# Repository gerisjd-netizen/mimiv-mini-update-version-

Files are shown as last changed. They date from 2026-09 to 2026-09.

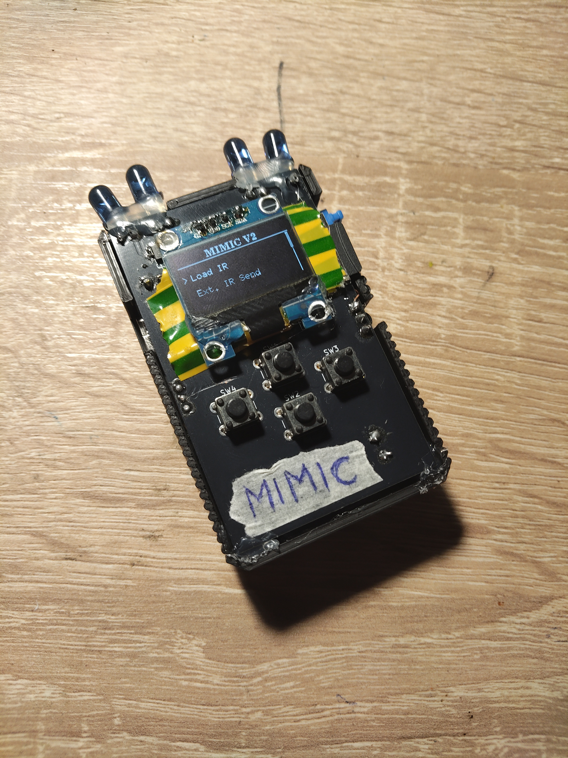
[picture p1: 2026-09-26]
mimic_mini/IMG_20260921_205225.jpg

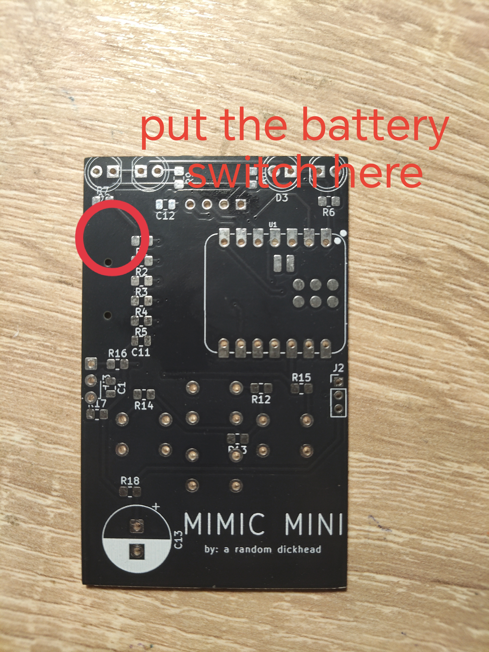
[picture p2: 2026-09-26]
mimic_mini/IMG_20260921_205933.jpg

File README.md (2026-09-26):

# MIMIC Mini - IR Cloner

MIMIC Mini is a compact infrared (IR) cloner and universal remote device. It is capable of reliably transmitting IR signals at ranges of up to 10–15 meters. It is fully compatible with Flipper Zero `.ir` files and provides up to 3 days of battery life under normal usage. Equipped with microSD card storage and an integrated receiver unit, it can record and save captured signals in both raw `.txt` and standard `.ir` formats.

---

## 🛠 Features

* **Extended Range:** Transmits IR signals up to 10–15 meters.
* **Flipper Zero Compatibility:** Natively supports `.ir` signal files.
* **Long Battery Life:** Up to 3 days of standard operational time.
* **Expandable Storage:** MicroSD card support for storing large databases of IR codes.
* **Signal Capture:** Built-in receiver capable of capturing and saving raw TXT or structured IR formats.

---

## 🏗 Housing & Assembly Instructions

1. **Belt Clip Attachment:**
   * The bill of materials (BOM) does not include the 3mm press-fit brass inserts or corresponding screws. 
   * The belt clip mount should be glued directly to the back of the enclosure for easy belt attachment.

2. **Display Insulation (CRITICAL):**
   * Before inserting the display, **apply insulating adhesive tape (e.g., Kapton or electrical tape) to the back of the display board**.
   * *Warning:* Failure to insulate the back of the display may cause a short circuit against the MicroSD card socket.

3. **IR LED Alignment:**
   * Pay close attention to the positioning and angles of the IR LEDs. 
   * If all LEDs are pointing straight forward, the transmission beam spread will be reduced, making it harder to aim at target devices. Angle them slightly outward to maximize signal coverage.

4. **Battery & Power Switch Wiring:**
   * Solder the battery directly to the `BAT` pads on the bottom of the ESP32-C3 board.
   * Wire the power switch in series with the positive battery lead to break the circuit.
   * Glue the power switch to the side of the PCB as demonstrated in the assembly photos.

---

## 📁 SD Card Structure & Usage

Upon inserting an SD card for the first time, the device will automatically generate three directories:
### 1. `saved_ir/`
* Captured IR signals are saved here. You can set the target capture format (`.ir` or `.txt`) in the device settings menu.
* Files in this folder can be renamed freely.
* If you place a multi-code `.ir` file in this folder, opening it on the device will display a sub-menu containing each individual code, allowing you to trigger them selectively one by one.

### 2. `universal/`
* If a multi-code `.ir` file is placed in the `universal` directory, the device will sequentially play back **all** IR codes inside the file one after another (e.g., universal power-off sequence). You will not be able to select individual codes in this mode.

---

## ⚙️ Settings

* **Transmitter Selection:** Through the system settings, you can toggle between using the internal IR transmitter array or an external IR module/emitter.

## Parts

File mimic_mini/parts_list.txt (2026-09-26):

100.337.50	4	TACT-65K-F
100.285.00	1	470uF/16V LOW ESR & IMP.
100.264.87	4	TSAL-6200
100.427.11	1	4.7uF / 25V
100.011.22	2	100 nF / 50V
100.496.54	8	SMD0805-10K-0.1%
100.012.50	4	SMD0805-22R-5%
100.449.24	1	100R 1%
100.011.43	2	SMD0805-100K-5%
100.011.72	1	SMD0805-33K-5%
100.011.56	1	SMD0805-1R-5%
100.461.70	1	TSOP38238
100.510.43	1	XIAO-ESP32-C3
100.483.04	1	D096-12864-I2C-GV-WH
100.329.15	1	ZL262-3SG
100.399.59	1	AO3400A
100.410.19	1	MCSP-Q-08-A-SG-T/R
100.399.65	1	BS-800-L
100.490.28	1	AKY0384-LP601730

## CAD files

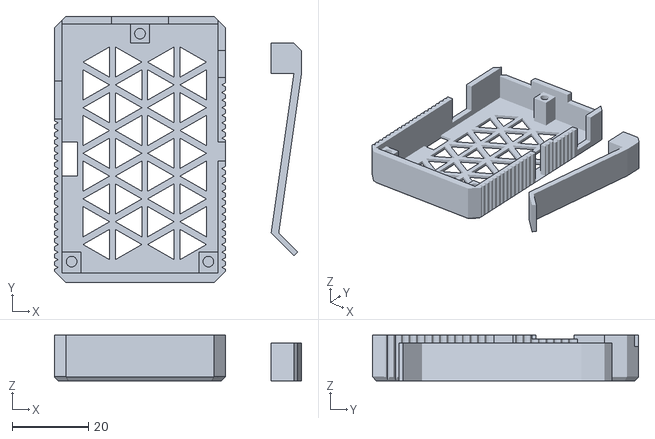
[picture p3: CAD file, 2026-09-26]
mimic_mini/mimic_mini_housing.stl
65.0 x 70.0 x 12.0

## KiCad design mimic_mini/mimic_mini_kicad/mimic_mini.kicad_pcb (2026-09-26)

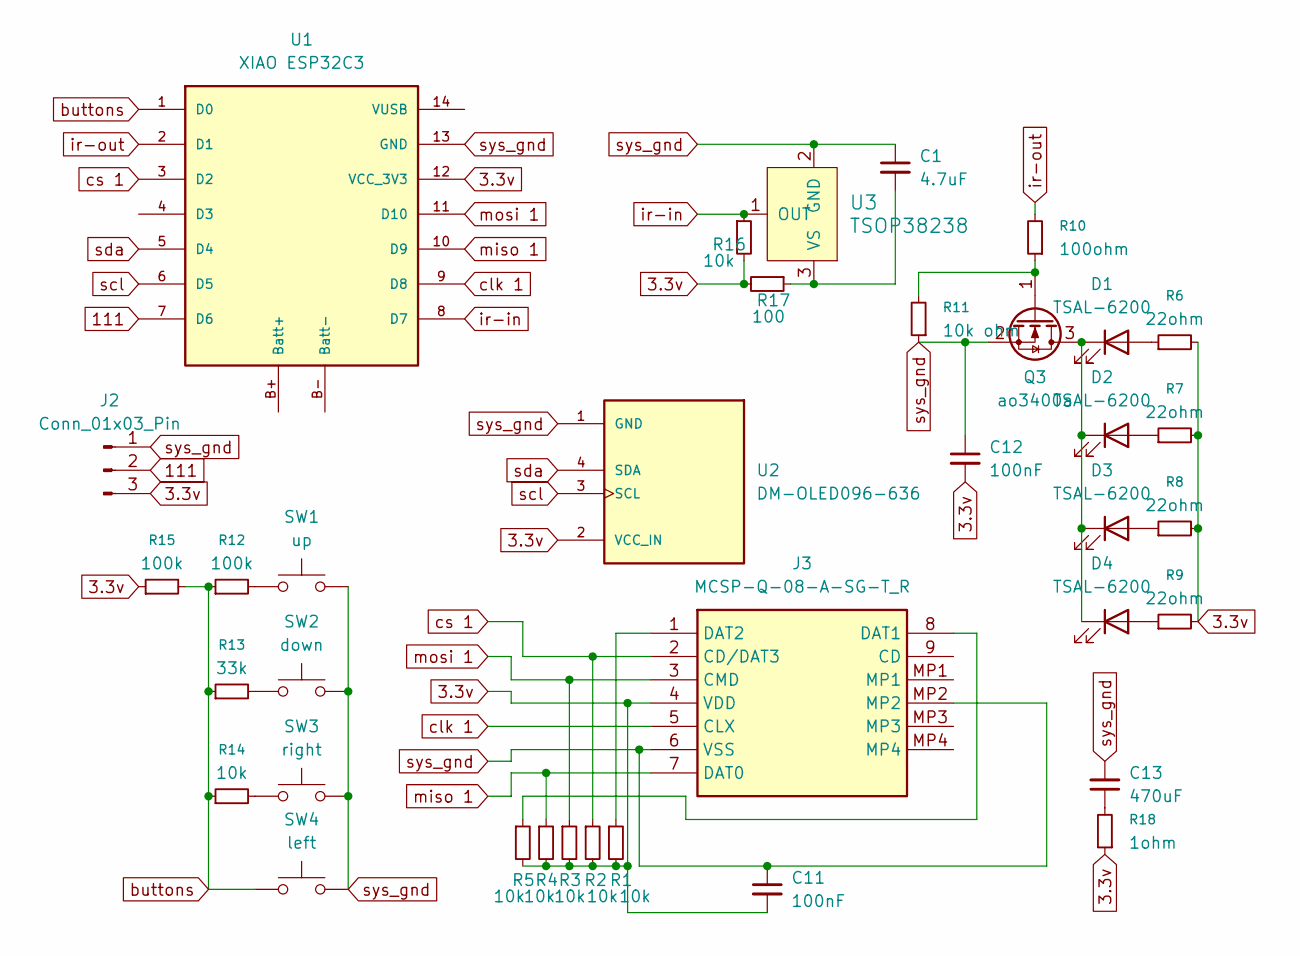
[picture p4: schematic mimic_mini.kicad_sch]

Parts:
C1: 4.7uF; C_0805_2012Metric
C11, C12: 100nF; C_0805_2012Metric
C13: 470uF; CP_Radial_D10.0mm_P3.80mm
D1, D2, D3, D4: TSAL-6200; LED_D5.0mm
J2: Conn_01x03_Pin; PinHeader_1x03_P2.54mm_Vertical
J3: MCSP-Q-08-A-SG-T_R; MCSPQ08ASGTR; Manufacturer_Part_Number MCSP-Q-08-A-SG-T/R
Q3: ao3400a; SOT-23
R1, R2, R3, R4, R5, R14, R16: 10k; R_0805_2012Metric_Pad1.20x1.40mm_HandSolder
R6, R7, R8, R9: 22ohm; R_0805_2012Metric_Pad1.20x1.40mm_HandSolder
R10: 100ohm; R_0805_2012Metric_Pad1.20x1.40mm_HandSolder
R11: 10k ohm; R_0805_2012Metric_Pad1.20x1.40mm_HandSolder
R12, R15: 100k; R_0805_2012Metric_Pad1.20x1.40mm_HandSolder
R13: 33k; R_0805_2012Metric_Pad1.20x1.40mm_HandSolder
R17: 100; R_0805_2012Metric_Pad1.20x1.40mm_HandSolder
R18: 1ohm; R_0805_2012Metric_Pad1.20x1.40mm_HandSolder
SW1: up; SW_PUSH_6mm
SW2: down; SW_PUSH_6mm
SW3: right; SW_PUSH_6mm
SW4: left; SW_PUSH_6mm
U1: XIAO ESP32C3; XIAO-ESP32-C3-DIP-SMD
U2: DM-OLED096-636; MODULE_DM-OLED096-636; PARTREV 2018-09-10
U3: TSOP38238; Vishay_MINICAST-3Pin; MPN TSOP38238; Digi-Key_PN 751-1227-ND

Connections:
3.3v: C11.2, C12.2, J2.3, J3.4 (VDD), R1.2, R2.2, R3.2, R4.2, R5.2, R6.2, R7.2, R8.2, R9.2, R15.1, R16.2, R17.2, R18.1, U1.12 (VCC_3V3), U2.2 (VCC_IN)
111: J2.2, U1.7 (D6)
unnamed: C13.1, R18.2
unnamed: D1.2 (A), R6.1
unnamed: D1.1 (K), D2.1 (K), D3.1 (K), D4.1 (K), Q3.3 (D)
unnamed: D2.2 (A), R7.1
unnamed: D3.2 (A), R8.1
unnamed: D4.2 (A), R9.1
unnamed: J3.8 (DAT1), R5.1
unnamed: J3.1 (DAT2), R1.1
unnamed: Q3.1 (G), R10.1, R11.2
unnamed: R12.2, SW1.1
unnamed: R13.2, SW2.1
unnamed: R14.2, SW3.1
unnamed: C1.2, R17.1, U3.3 (VS)
buttons: R12.1, R13.1, R14.1, R15.2, SW4.1, U1.1 (D0)
clk 1: J3.5 (CLX), U1.9 (D8)
cs 1: J3.2 (CD/DAT3), R2.1, U1.3 (D2)
ir-in: R16.1, U1.8 (D7), U3.1 (OUT)
ir-out: R10.2, U1.2 (D1)
miso 1: J3.7 (DAT0), R4.1, U1.10 (D9)
mosi 1: J3.3 (CMD), R3.1, U1.11 (D10)
scl: U1.6 (D5), U2.3 (SCL)
sda: U1.5 (D4), U2.4 (SDA)
sys_gnd: C1.1, C11.1, C12.1, C13.2, J2.1, J3.6 (VSS), J3.MP2, Q3.2 (S), R11.1, SW1.2, SW2.2, SW3.2, SW4.2, U1.13 (GND), U2.1 (GND), U3.2 (GND)

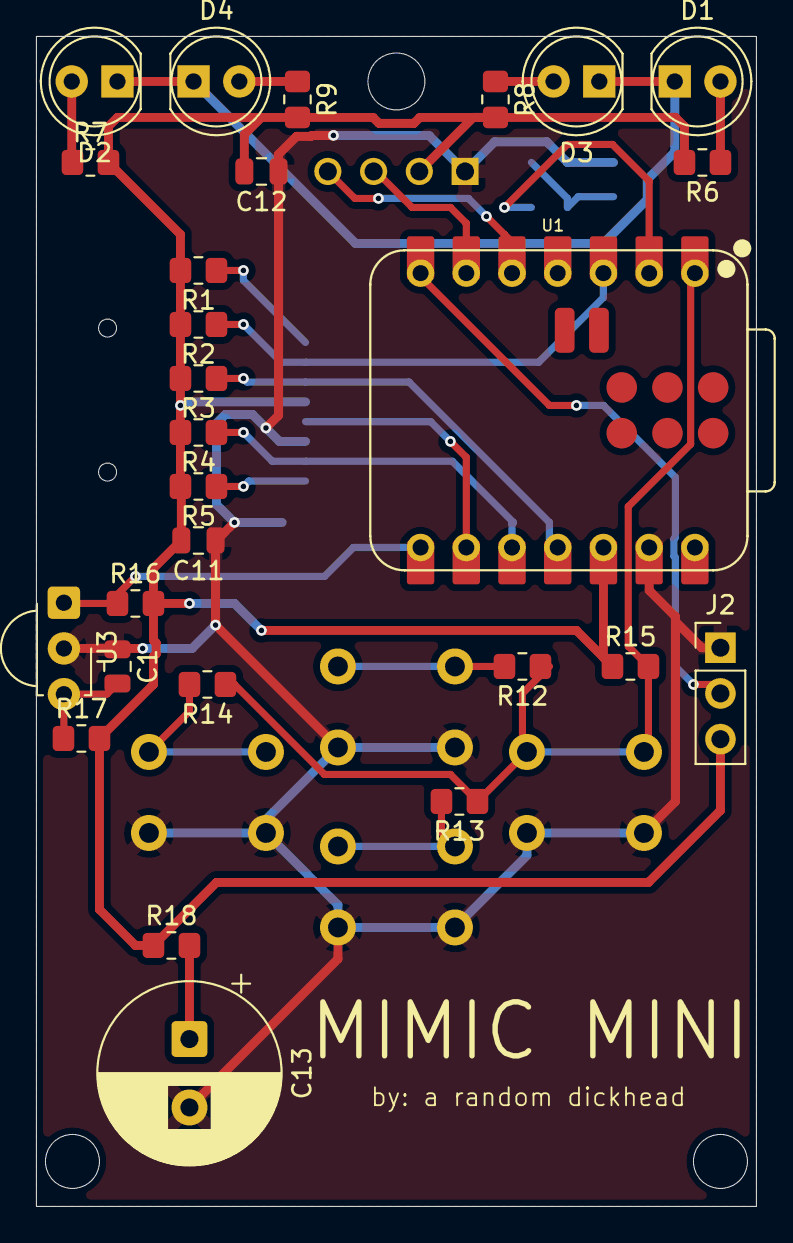
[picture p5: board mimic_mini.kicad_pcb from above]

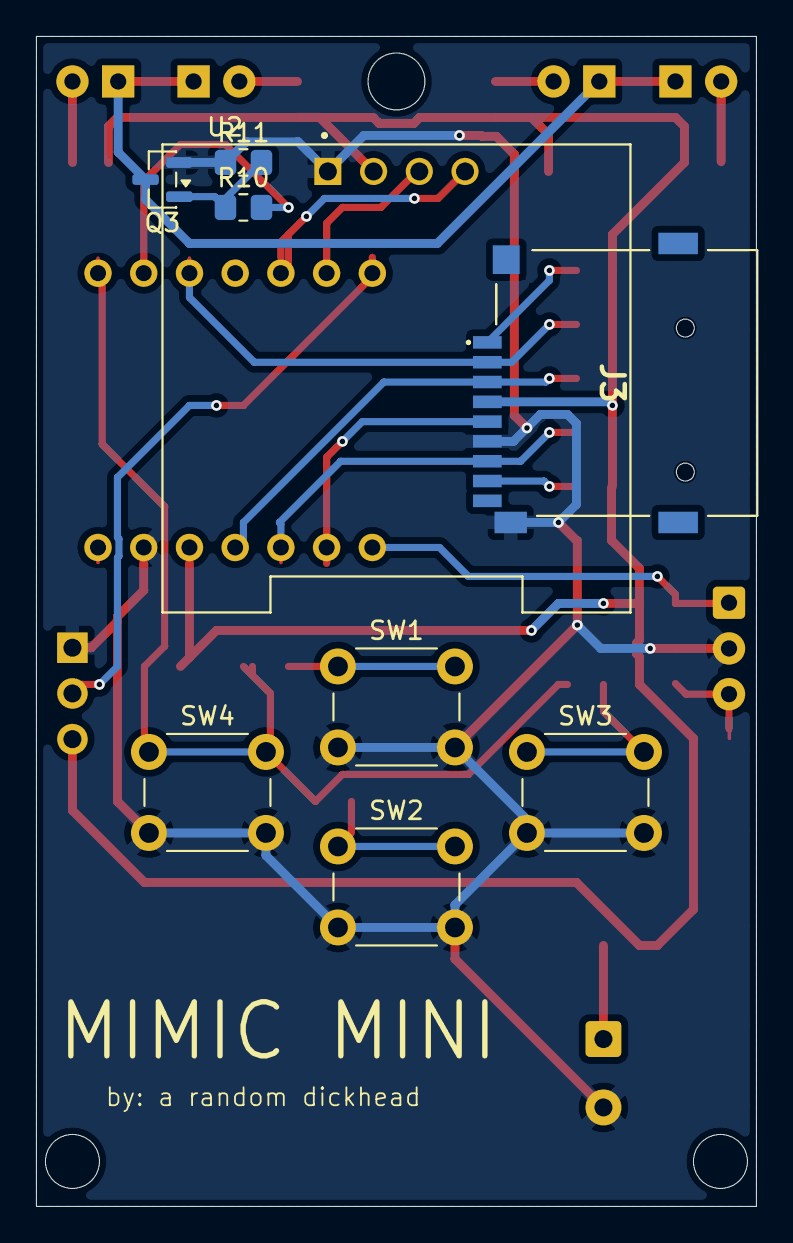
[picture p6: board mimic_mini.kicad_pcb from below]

Board: 2 copper layers, 40.0 x 65.0 mm, 36 parts (9 on the bottom side), 25 nets.

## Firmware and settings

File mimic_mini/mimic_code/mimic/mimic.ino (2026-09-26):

#include <Arduino.h>
#include <SPI.h>
#include <SD.h>
#include <U8g2lib.h>
#include <Wire.h>
#include <EEPROM.h>
#include "esp_sleep.h"

// --- EEPROM CÍMEK ---
#define EEPROM_SIZE 2
#define EEPROM_SAVE_FORMAT_ADDR 0
#define EEPROM_LED_PIN_ADDR 1

// --- IRREMOTE CONFIGURATION ---
#define IR_SEND_INTERNAL_PIN 3   // Belső IR adó LED: GPIO 3
#define IR_SEND_EXTERNAL_PIN 21  // Külső IR adó adatvonala: GPIO 21 (D6)
#define IR_RECEIVE_PIN 20        // IR vevő modul: GPIO 20
#define RAW_BUFFER_LENGTH 400    // Puffer méret a nyers pulzusokhoz

// --- SEBESSÉG BEÁLLÍTÁS ---
const uint16_t IR_GAP_MS = 50; 

#include <IRremote.hpp>

// --- PINOUT DEFINITIONS ---
#define SD_CS   4   // D2 láb = GPIO 4
#define SD_CLK  8   // D8 láb = GPIO 8
#define SD_MISO 9   // D9 láb = GPIO 9
#define SD_MOSI 10  // D10 láb = GPIO 10
#define ANALOG_PIN 2 // Gomb-létra: GPIO 2 (ADC1_CH2)

// Deep sleep inaktivitási időkorlát (30 másodperc)
#define SLEEP_TIMEOUT_MS 30000 
uint32_t lastActivityTime = 0;

// SD Kártya állapotának figyelése
bool sdInitialized = false;

// OLED Kijelző (XIAO ESP32-C3: SDA=6, SCL=7)
U8G2_SSD1306_128X64_NONAME_F_HW_I2C u8g2(U8G2_R0, U8X8_PIN_NONE);

// --- AUTO-REPEAT GOMB MÁTRIX VÁLTOZÓK ---
enum ButtonType { BTN_NONE, BTN_LEFT, BTN_RIGHT, BTN_DOWN, BTN_UP };

ButtonType lastPhysicalButton = BTN_NONE;
unsigned long buttonPressStart = 0;
unsigned long lastRepeatTime = 0;
bool isHolding = false;

const unsigned long HOLD_DELAY_MS = 350;     // Ennyi nyomva tartás után indul a gyorstüzelés
const unsigned long REPEAT_INTERVAL_MS = 100; // Ismétlési sebesség (ms)

// Gomb trigger jelzők a loop-nak
bool rightTriggered = false;
bool downTriggered  = false;
bool leftTriggered   = false;
bool upTriggered     = false;

// Nyers gombállapotok az olyan folyamatos mozgásokhoz, mint a Pong
bool rightRaw = false;
bool downRaw  = false;
bool leftRaw   = false;
bool upRaw     = false;

// SD Fájllista (IR, Univ és Jegyzetekhez)
#define MAX_FILES 50
String fileList[MAX_FILES];
int totalFiles = 0;
int selectedIndex = 0;

// Több jelet tartalmazó fájlok almenüje
#define MAX_SUB_SIGNALS 40
String subSignalNames[MAX_SUB_SIGNALS];
int totalSubSignals = 0;
int selectedSubIndex = 0;
String currentMultiFilePath = "";

// Jegyzet megjelenítéshez sorok
#define MAX_NOTE_LINES 100
String noteLines[MAX_NOTE_LINES];
int totalNoteLines = 0;
int noteScrollIndex = 0;

// Beállítások opciók
bool saveAsFlipper = true; // true = Flipper .ir, false = Raw .txt
bool useExternalIR = false; // true = External, false = Internal

// Rendszerállapotok
enum SystemState {
  MAIN_MENU,
  IR_MENU,
  LOAD_IR_LIST,
  LOAD_UNIV_LIST,
  SUB_IR_LIST,
  SAVE_IR_WAIT,
  LOAD_NOTE_LIST,
  VIEW_NOTE,
  SETTINGS_MENU,
  GAME_PONG,
  STATUS_MSG
};

SystemState currentState = MAIN_MENU;

// Menü indexek
int mainMenuIndex = 0; 
const int MAIN_MENU_TOTAL = 4; // 0=IR Signal, 1=Notes, 2=Games, 3=Settings

int irMenuIndex = 0;
const int IR_MENU_TOTAL = 3; // 0=Load IR, 1=Universal IR, 2=Save IR

int settingsMenuIndex = 0;
const int SETTINGS_MENU_TOTAL = 2; // 0=IR LED, 1=Save Format

String statusMessage = "";
uint32_t statusTimer = 0;

// --- PONG JÁTÉK VÁLTOZÓK ---
int playerY = 24;
int cpuY = 24;
const int paddleHeight = 16;
const int paddleWidth = 3;

float ballX = 64.0;
float ballY = 32.0;
float ballSpeedX = 2.5;
float ballSpeedY = 1.5;

int playerScore = 0;
int cpuScore = 0;

// --- PROTOTÍPUSOK ---
void playAllSignalsInUniversalFile(String filePath);

// --- EEPROM BEÁLLÍTÁSOK BETÖLTÉSE ÉS MENTÉSE ---
void loadSettings() {
  if (!EEPROM.begin(EEPROM_SIZE)) {
    Serial.println("EEPROM Init Failed!");
    return;
  }
  
  uint8_t formatVal = EEPROM.read(EEPROM_SAVE_FORMAT_ADDR);
  saveAsFlipper = (formatVal == 1) ? true : false;

  uint8_t ledVal = EEPROM.read(EEPROM_LED_PIN_ADDR);
  useExternalIR = (ledVal == 1) ? true : false;
}

void saveSettings() {
  EEPROM.write(EEPROM_SAVE_FORMAT_ADDR, saveAsFlipper ? 1 : 0);
  EEPROM.write(EEPROM_LED_PIN_ADDR, useExternalIR ? 1 : 0);
  EEPROM.commit();
}

// --- DEEP SLEEP INDÍTÁSA ---
void goToSleep() {
  u8g2.clearBuffer();
  u8g2.sendBuffer();
  
  Wire.beginTransmission(0x3C);
  Wire.write(0x00);
  Wire.write(0xAE);
  Wire.endTransmission();

  pinMode(ANALOG_PIN, INPUT_PULLUP);
  delay(50); 

  esp_deep_sleep_enable_gpio_wakeup(1ULL << ANALOG_PIN, ESP_GPIO_WAKEUP_GPIO_LOW);
  esp_deep_sleep_start();
}

// --- ANALÓG GOMB-LÉTRA BEOLVASÁSA AUTO-REPEAT FUNKCIÓVAL ---
void readButtons() {
  rightTriggered = false;
  downTriggered  = false;
  leftTriggered   = false;
  upTriggered     = false;

  rightRaw = false;
  downRaw  = false;
  leftRaw   = false;
  upRaw     = false;

  uint32_t mVolts = analogReadMilliVolts(ANALOG_PIN);
  float voltage = mVolts / 1000.0;

  ButtonType currentPhysicalButton = BTN_NONE;

  if (voltage < 0.10) {
    currentPhysicalButton = BTN_LEFT;
    leftRaw = true;
  } else if (voltage >= 0.15 && voltage <= 0.45) {
    currentPhysicalButton = BTN_RIGHT;
    rightRaw = true;
  } else if (voltage >= 0.65 && voltage <= 0.95) {
    currentPhysicalButton = BTN_DOWN;
    downRaw = true;
  } else if (voltage >= 1.45 && voltage <= 1.85) {
    currentPhysicalButton = BTN_UP;
    upRaw = true;
  }

  unsigned long now = millis();

  if (currentPhysicalButton != BTN_NONE) {
    lastActivityTime = now; // Inaktivitás számláló frissítése

    if (currentPhysicalButton != lastPhysicalButton) {
      // ÚJ GOMBNYOMÁS! Azonnali trigger
      lastPhysicalButton = currentPhysicalButton;
      buttonPressStart = now;
      lastRepeatTime = now;
      isHolding = false;

      if (currentPhysicalButton == BTN_LEFT)  leftTriggered = true;
      if (currentPhysicalButton == BTN_RIGHT) rightTriggered = true;
      if (currentPhysicalButton == BTN_DOWN)  downTriggered = true;
      if (currentPhysicalButton == BTN_UP)    upTriggered = true;
    } 
    else {
      // FOLYAMATOSAN NYOMVA TARTVA
      if (!isHolding && (now - buttonPressStart >= HOLD_DELAY_MS)) {
        isHolding = true;
        lastRepeatTime = now;

        if (currentPhysicalButton == BTN_LEFT)  leftTriggered = true;
        if (currentPhysicalButton == BTN_RIGHT) rightTriggered = true;
        if (currentPhysicalButton == BTN_DOWN)  downTriggered = true;
        if (currentPhysicalButton == BTN_UP)    upTriggered = true;
      } 
      else if (isHolding && (now - lastRepeatTime >= REPEAT_INTERVAL_MS)) {
        lastRepeatTime = now;

        if (currentPhysicalButton == BTN_LEFT)  leftTriggered = true;
        if (currentPhysicalButton == BTN_RIGHT) rightTriggered = true;
        if (currentPhysicalButton == BTN_DOWN)  downTriggered = true;
        if (currentPhysicalButton == BTN_UP)    upTriggered = true;
      }
    }
  } else {
    // ELENGEDVE
    lastPhysicalButton = BTN_NONE;
    isHolding = false;
  }
}

// --- SD KÁRTYÁRÓL FÁJLLISTA BEOLVASÁSA ---
void loadFileListFromFolder(const char* folderPath) {
  totalFiles = 0;
  selectedIndex = 0;

  if (!sdInitialized) {
    statusMessage = "NO SD CARD!";
    currentState = STATUS_MSG;
    statusTimer = millis();
    return;
  }

  if (!SD.exists(folderPath)) {
    SD.mkdir(folderPath);
  }

  File dir = SD.open(folderPath);
  if (!dir || !dir.isDirectory()) return;

  dir.rewindDirectory();

  while (true) {
    File entry = dir.openNextFile();
    if (!entry) break;

    String fname = String(entry.name());
    bool isDir = entry.isDirectory();
    entry.close();

    if (!isDir) {
      int lastSlash = fname.lastIndexOf('/');
      if (lastSlash >= 0) {
        fname = fname.substring(lastSlash + 1);
      }

      String fnameLower = fname;
      fnameLower.toLowerCase();

      if ((fnameLower.endsWith(".txt") || fnameLower.endsWith(".ir")) && !fname.startsWith(".")) {
        if (totalFiles < MAX_FILES) {
          fileList[totalFiles] = fname;
          totalFiles++;
        }
      }
    }
  }
  dir.close();
}

// --- JEGYZET BEOLVASÁSA ÉS TÖRDELÉSE ---
void loadAndWrapNote(String filename) {
  totalNoteLines = 0;
  noteScrollIndex = 0;

  if (!sdInitialized) return;

  String filePath = "/notes/" + filename;
  File noteFile = SD.open(filePath, FILE_READ);

  if (!noteFile) return;

  u8g2.setFont(u8g2_font_6x10_tr);
  int maxPixelWidth = 120; 

  String currentLine = "";

  while (noteFile.available() && totalNoteLines < MAX_NOTE_LINES) {
    char c = noteFile.read();

    if (c == '\r') continue;

    if (c == '\n') {
      noteLines[totalNoteLines++] = currentLine;
      currentLine = "";
      continue;
    }

    String testLine = currentLine + c;
    if (u8g2.getStrWidth(testLine.c_str()) <= maxPixelWidth) {
      currentLine = testLine;
    } else {
      if (currentLine.length() > 0) {
        noteLines[totalNoteLines++] = currentLine;
      }
      currentLine = String(c);
    }
  }

  if (currentLine.length() > 0 && totalNoteLines < MAX_NOTE_LINES) {
    noteLines[totalNoteLines++] = currentLine;
  }

  noteFile.close();
}

// --- SORSZÁMOZÁS AZ ÚJ IR FÁJLNAK ---
int getNextFileNumber() {
  int maxNum = 0;
  for (int i = 0; i < totalFiles; i++) {
    String fname = fileList[i];
    int dotIdx = fname.indexOf('.');
    if (dotIdx > 0) {
      int num = fname.substring(0, dotIdx).toInt();
      if (num > maxNum) {
        maxNum = num;
      }
    }
  }
  return maxNum + 1;
}

// --- IR JEL MENTÉSE ---
void saveIRSignal() {
  if (!sdInitialized) {
    statusMessage = "NO SD CARD!";
    currentState = STATUS_MSG;
    statusTimer = millis();
    return;
  }

  loadFileListFromFolder("/ir_files"); 
  int newNum = getNextFileNumber();
  
  if (saveAsFlipper && IrReceiver.decodedIRData.protocol != UNKNOWN) {
    String filePath = "/ir_files/" + String(newNum) + ".ir";
    File irFile = SD.open(filePath, FILE_WRITE);

    if (irFile) {
      irFile.println("Filetype: IR signals file");
      irFile.println("Version: 1");
      irFile.println("# ");
      irFile.print("name: ");
      irFile.println(String(newNum));
      irFile.println("type: parsed");

      String protName = getProtocolString(IrReceiver.decodedIRData.protocol);
      irFile.print("protocol: ");
      irFile.println(protName);

      uint32_t addr = IrReceiver.decodedIRData.address;
      uint32_t cmd  = IrReceiver.decodedIRData.command;

      char addrBuf[12];
      char cmdBuf[12];
      snprintf(addrBuf, sizeof(addrBuf), "%02X 00 00 00", (unsigned int)(addr & 0xFF));
      snprintf(cmdBuf, sizeof(cmdBuf), "%02X 00 00 00", (unsigned int)(cmd & 0xFF));

      irFile.print("address: ");
      irFile.println(addrBuf);
      irFile.print("command: ");
      irFile.println(cmdBuf);

      irFile.close();
      statusMessage = "SAVED: " + String(newNum) + ".ir";
    } else {
      statusMessage = "SD WRITE ERROR!";
    }
  } 
  else {
    uint16_t length = IrReceiver.irparams.rawlen - 1;
    if (length > RAW_BUFFER_LENGTH) length = RAW_BUFFER_LENGTH;

    String filePath = "/ir_files/" + String(newNum) + ".txt";
    File irFile = SD.open(filePath, FILE_WRITE);

    if (irFile) {
      for (unsigned int i = 1; i <= length; i++) {
        irFile.print(IrReceiver.irparams.rawbuf[i] * MICROS_PER_TICK);
        if (i < length) irFile.print(",");
      }
      irFile.close();
      statusMessage = "SAVED: " + String(newNum) + ".txt";
    } else {
      statusMessage = "SD WRITE ERROR!";
    }
  }

  currentState = STATUS_MSG;
  statusTimer = millis();
}

// --- SCROLLBAR RAJZOLÁSA ---
void drawScrollbar(int currentIdx, int totalItems, int visibleItems) {
  if (totalItems <= visibleItems) return;

  int trackX = 124;
  int trackY = 16;
  int trackHeight = 46;
  int trackWidth = 3;

  u8g2.drawVLine(trackX + 1, trackY, trackHeight);

  int thumbHeight = max(6, (trackHeight * visibleItems) / totalItems);
  int thumbY = trackY + ((trackHeight - thumbHeight) * currentIdx) / (totalItems - 1);

  u8g2.drawBox(trackX, thumbY, trackWidth, thumbHeight);
}

// --- FLIPPER HEX PARSER ---
uint32_t parseFlipperHexBytes(String hexStr) {
  uint32_t result = 0;
  int byteIdx = 0;
  hexStr.trim();
  
  while (hexStr.length() > 0 && byteIdx < 4) {
    int spaceIdx = hexStr.indexOf(' ');
    String byteStr = (spaceIdx != -1) ? hexStr.substring(0, spaceIdx) : hexStr;
    if (spaceIdx != -1) {
      hexStr = hexStr.substring(spaceIdx + 1);
      hexStr.trim();
    } else {
      hexStr = "";
    }
    
    uint32_t val = strtoul(byteStr.c_str(), NULL, 16);
    result |= (val << (byteIdx * 8));
    byteIdx++;
  }
  return result;
}

// --- IR KÜLDŐ ---
void executeParsedIR(String protocol, uint32_t address, uint32_t command) {
  protocol.toLowerCase();
  protocol.trim();
  
  if (protocol == "nec" || protocol == "necext") {
    IrSender.sendNEC(address & 0xFFFF, command & 0xFFFF, 0);
  } 
  else if (protocol == "samsung" || protocol == "samsung32") {
    IrSender.sendSamsung(address & 0xFFFF, command & 0xFFFF, 0);
  } 
  else if (protocol == "sirc" || protocol == "sony") {
    IrSender.sendSony(address & 0xFFFF, command & 0xFF, 2);
  } 
  else if (protocol == "rc5") {
    IrSender.sendRC5(address & 0xFF, command & 0xFF, 0);
  } 
  else if (protocol == "rc6") {
    IrSender.sendRC6(address & 0xFF, command & 0xFF, 0);
  }
}

// --- MEGSZÁMOLJA A JELEKET EGY FÁJLBAN ---
int countAndParseSignalsInFile(String filePath) {
  totalSubSignals = 0;
  File irFile = SD.open(filePath, FILE_READ);
  if (!irFile) return 0;

  while (irFile.available()) {
    String line = irFile.readStringUntil('\n');
    line.trim();

    if (line.startsWith("Name: ") || line.startsWith("name: ")) {
      if (totalSubSignals < MAX_SUB_SIGNALS) {
        subSignalNames[totalSubSignals] = line.substring(6);
        totalSubSignals++;
      }
    }
  }
  irFile.close();
  return totalSubSignals;
}
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
void loop() {
  readButtons();

  if (millis() - lastActivityTime > SLEEP_TIMEOUT_MS) {
    goToSleep();
  }

  if (currentState == STATUS_MSG && (millis() - statusTimer > 1500)) {
    currentState = MAIN_MENU; 
  }

  // --- 1. MAIN MENU ---
  if (currentState == MAIN_MENU) {
    if (downTriggered) {
      mainMenuIndex = (mainMenuIndex + 1) % MAIN_MENU_TOTAL;
    } 
    else if (upTriggered) {
      mainMenuIndex = (mainMenuIndex - 1 + MAIN_MENU_TOTAL) % MAIN_MENU_TOTAL;
    } 
    else if (rightTriggered) {
      if (mainMenuIndex == 0) {
        currentState = IR_MENU;
        irMenuIndex = 0;
      }
      else if (mainMenuIndex == 1) {
        loadFileListFromFolder("/notes");
        currentState = LOAD_NOTE_LIST;
      }
      else if (mainMenuIndex == 2) {
        resetPongGame();
        currentState = GAME_PONG;
      }
      else if (mainMenuIndex == 3) {
        currentState = SETTINGS_MENU;
        settingsMenuIndex = 0;
      }
    }
  }

  // --- 2. IR MENU ---
  else if (currentState == IR_MENU) {
    if (downTriggered) {
      irMenuIndex = (irMenuIndex + 1) % IR_MENU_TOTAL;
    } 
    else if (upTriggered) {
      irMenuIndex = (irMenuIndex - 1 + IR_MENU_TOTAL) % IR_MENU_TOTAL;
    } 
    else if (rightTriggered) {
      if (irMenuIndex == 0) {
        loadFileListFromFolder("/ir_files");
        currentState = LOAD_IR_LIST;
      } 
      else if (irMenuIndex == 1) {
        loadFileListFromFolder("/universal");
        currentState = LOAD_UNIV_LIST;
      } 
      else if (irMenuIndex == 2) {
        currentState = SAVE_IR_WAIT;
        IrReceiver.start();
      }
    } 
    else if (leftTriggered) {
      currentState = MAIN_MENU;
    }
  }

  // --- 3. SETTINGS MENU ---
  else if (currentState == SETTINGS_MENU) {
    if (downTriggered) {
      settingsMenuIndex = (settingsMenuIndex + 1) % SETTINGS_MENU_TOTAL;
    } 
    else if (upTriggered) {
      settingsMenuIndex = (settingsMenuIndex - 1 + SETTINGS_MENU_TOTAL) % SETTINGS_MENU_TOTAL;
    } 
    else if (rightTriggered) {
      if (settingsMenuIndex == 0) {
        useExternalIR = !useExternalIR;
        saveSettings();
      } else if (settingsMenuIndex == 1) {
        saveAsFlipper = !saveAsFlipper;
        saveSettings();
      }
    } 
    else if (leftTriggered) {
      currentState = MAIN_MENU;
    }
  }

  // --- 4. LOAD IR LIST / LOAD UNIV LIST ---
  else if (currentState == LOAD_IR_LIST || currentState == LOAD_UNIV_LIST) {
    if (downTriggered) {
      if (totalFiles > 0) selectedIndex = (selectedIndex + 1) % totalFiles;
    } 
    else if (upTriggered) {
      if (totalFiles > 0) selectedIndex = (selectedIndex - 1 + totalFiles) % totalFiles;
    } 
    else if (rightTriggered) {
      if (totalFiles > 0) {
        if (currentState == LOAD_IR_LIST) {
          handleIRFileSelect(fileList[selectedIndex]);
        } else if (currentState == LOAD_UNIV_LIST) {
          handleUniversalFileSelect(fileList[selectedIndex]);
        }
      }
    } 
    else if (leftTriggered) {
      currentState = IR_MENU; 
    }
  }

  // --- 5. SUB IR LIST ---
  else if (currentState == SUB_IR_LIST) {
    if (downTriggered) {
      if (totalSubSignals > 0) selectedSubIndex = (selectedSubIndex + 1) % totalSubSignals;
    } 
    else if (upTriggered) {
      if (totalSubSignals > 0) selectedSubIndex = (selectedSubIndex - 1 + totalSubSignals) % totalSubSignals;
    } 
    else if (rightTriggered) {
      if (totalSubSignals > 0) processAndSendIRFile(currentMultiFilePath, subSignalNames[selectedSubIndex], selectedSubIndex);
    } 
    else if (leftTriggered) {
      currentState = LOAD_IR_LIST;
    }
  }

  // --- 6. LOAD NOTE LIST ---
  else if (currentState == LOAD_NOTE_LIST) {
    if (downTriggered) {
      if (totalFiles > 0) selectedIndex = (selectedIndex + 1) % totalFiles;
    } 
    else if (upTriggered) {
      if (totalFiles > 0) selectedIndex = (selectedIndex - 1 + totalFiles) % totalFiles;
    } 
    else if (rightTriggered) {
      if (totalFiles > 0) {
        loadAndWrapNote(fileList[selectedIndex]);
        currentState = VIEW_NOTE;
      }
    } 
    else if (leftTriggered) {
      currentState = MAIN_MENU;
    }
  }

  // --- 7. VIEW NOTE ---
  else if (currentState == VIEW_NOTE) {
    if (downTriggered) {
      if (noteScrollIndex + 4 < totalNoteLines) noteScrollIndex++;
    } 
    else if (upTriggered) {
      if (noteScrollIndex > 0) noteScrollIndex--;
    } 
    else if (leftTriggered) {
      currentState = LOAD_NOTE_LIST;
    }
  }

  // --- 8. SAVE IR WAIT ---
  else if (currentState == SAVE_IR_WAIT) {
    if (IrReceiver.decode()) {
      saveIRSignal();
      IrReceiver.resume();
    }

    if (leftTriggered) {
      currentState = IR_MENU;
    }
  }

  // --- 9. PONG GAME ---
  else if (currentState == GAME_PONG) {
    updateAndDrawPong();

    if (leftTriggered) {
      currentState = MAIN_MENU;
    }
  }

  // --- DISPLAY REFRESH ---
  if (currentState != GAME_PONG) {
    updateDisplay();
  }

  delay(20);
}

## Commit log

2026-09-26 Add files via upload
    Key Features
    IR Signal Capture & Transmission: Read raw and protocol-based IR codes (NEC, RC5, Sony, etc.) from standard remote controls and replay them with high-power IR transmitter LEDs.
    MicroSD Card Storage: Store captured IR profiles, custom button maps, and .ir library files directly onto a MicroSD card for long-term storage and quick access.
    OLED Interface: An onboard OLED display provides an intuitive interface for menu navigation, protocol inspection, and device status.
    Ultra-Compact Form Factor: Custom KiCad PCB layout optimized for maximum efficiency in a tiny footprint.
    ESP32-C3 Powered: High performance with low power consu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
    [mimic_mini.kicad_pcb, mimic_mini.kicad_sch, mimic_mini_housing.stl]
2026-09-26 Add README for MIMIC Mini IR Cloner
    Added detailed information about the MIMIC Mini IR cloner, including features, assembly instructions, and SD card usage.
